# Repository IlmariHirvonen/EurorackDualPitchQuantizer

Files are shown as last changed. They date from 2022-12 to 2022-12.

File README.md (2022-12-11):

# EurorackDualPitchQuantizer
A simple Arduino and MCP4725 DAC based pitch quantizer. It might not be the best designed module or it might not work at all yet. I have yet to assemble a working unit or program the non test firmware for the microcontroller. I'll update this as the project goes along.

### Licenses
The license for hardware is under the hardware folder and for software under software folder. But in short:
Software: GPL3.0.
Hardware: CERN-OHL-S v2

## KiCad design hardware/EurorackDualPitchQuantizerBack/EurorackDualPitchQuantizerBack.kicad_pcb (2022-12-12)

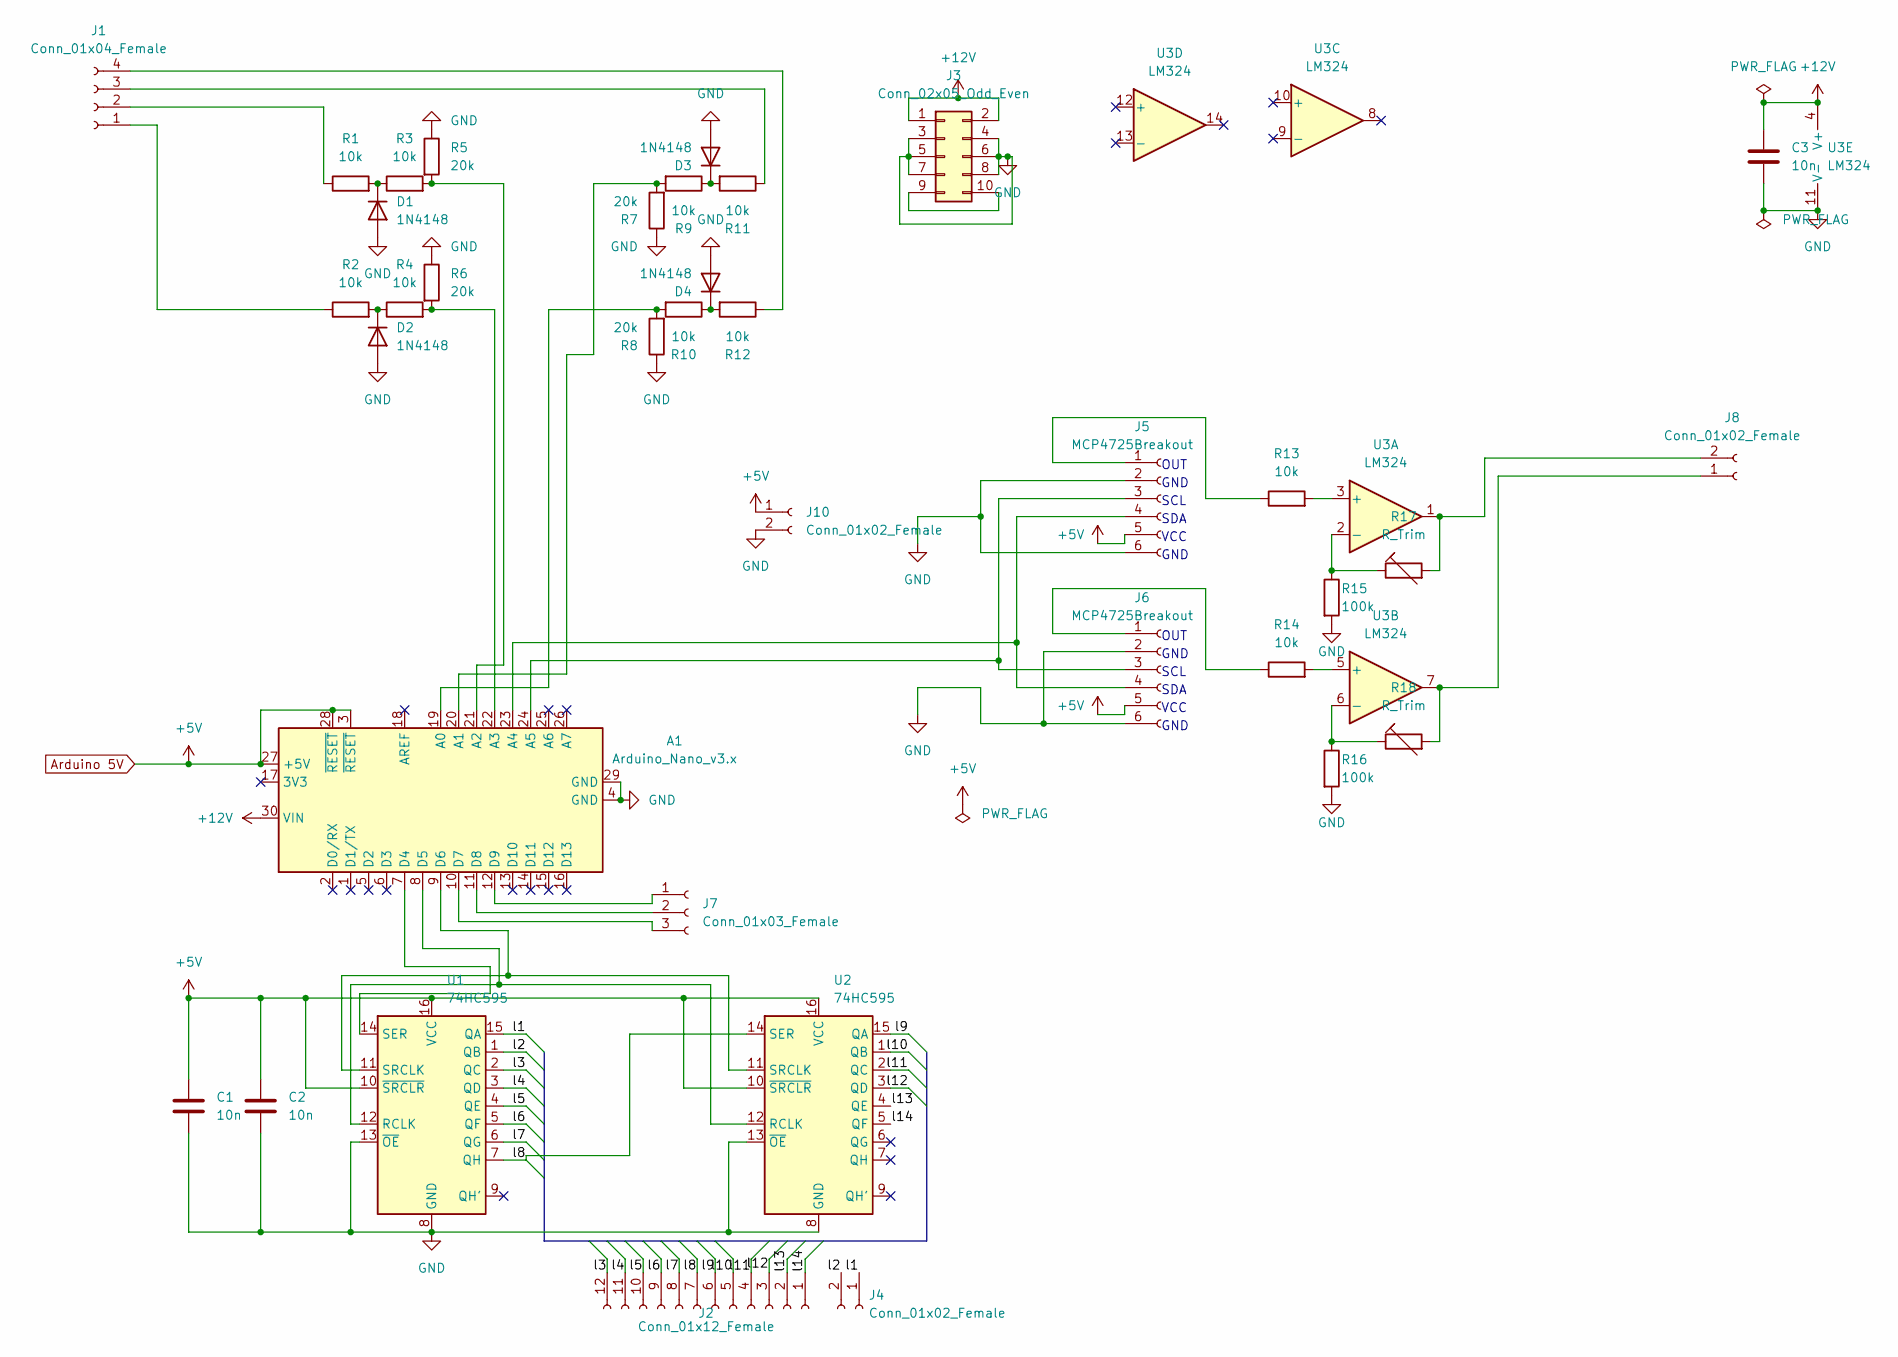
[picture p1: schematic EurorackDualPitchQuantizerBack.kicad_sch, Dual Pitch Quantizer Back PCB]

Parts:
A1: Arduino_Nano_v3.x; Arduino_Nano
C1, C2, C3: 10n; C_Disc_D3.0mm_W2.0mm_P2.50mm
D1, D2, D3, D4: 1N4148; D_DO-35_SOD27_P7.62mm_Horizontal
J1: Conn_01x04_Female; PinSocket_1x04_P2.54mm_Vertical
J2: Conn_01x12_Female; PinSocket_1x12_P2.54mm_Vertical
J3: Conn_02x05_Odd_Even; PinHeader_2x05_P2.54mm_Vertical
J4, J8: Conn_01x02_Female; PinSocket_1x02_P2.54mm_Vertical
J5, J6: MCP4725Breakout; PinSocket_1x06_P2.54mm_Vertical
J7: Conn_01x03_Female; PinHeader_1x03_P2.54mm_Vertical
J10: Conn_01x02_Female; PinHeader_1x02_P2.54mm_Vertical
R1, R2, R3, R4, R9, R10, R11, R12, R13, R14: 10k; R_Axial_DIN0207_L6.3mm_D2.5mm_P7.62mm_Horizontal
R5, R6, R7, R8: 20k; R_Axial_DIN0207_L6.3mm_D2.5mm_P7.62mm_Horizontal
R15, R16: 100k; R_Axial_DIN0207_L6.3mm_D2.5mm_P7.62mm_Horizontal
R17, R18: R_Trim; PinHeader_1x03_P2.54mm_Vertical
U1, U2: 74HC595; DIP-16_W7.62mm_Socket
U3: LM324; DIP-14_W7.62mm_Socket

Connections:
+12V: A1.30 (VIN), C3.1, J3.1, J3.2, U3.4 (V+)
/l1: J4.1, U1.15 (QA)
/l2: J4.2, U1.1 (QB)
/l3: J2.12, U1.2 (QC)
/l4: J2.11, U1.3 (QD)
/l5: J2.10, U1.4 (QE)
/l6: J2.9, U1.5 (QF)
/l7: J2.8, U1.6 (QG)
/l8: J2.7, U1.7 (QH), U2.14 (SER)
/l9: J2.6, U2.15 (QA)
/l10: J2.5, U2.1 (QB)
/l11: J2.4, U2.2 (QC)
/l12: J2.3, U2.3 (QD)
/l13: J2.2, U2.4 (QE)
/l14: J2.1, U2.5 (QF)
Arduino 5V: A1.3 (~RESET), A1.27 (+5V), A1.28 (~RESET), C1.1, C2.1, J5.5, J6.5, J10.1, U1.10 (~SRCLR), U1.16 (VCC), U2.10 (~SRCLR), U2.16 (VCC)
GND: A1.4 (GND), A1.29 (GND), C1.2, C2.2, C3.2, D1.2 (A), D2.2 (A), D3.2 (A), D4.2 (A), J3.3, J3.4, J3.5, J3.6, J3.7, J3.8, J5.2, J5.6, J6.2, J6.6, J10.2, R5.1, R6.1, R7.1, R8.1, R15.2, R16.2, U1.8 (GND), U1.13 (~OE), U2.8 (GND), U2.13 (~OE), U3.11 (V-)
unnamed: A1.7 (D4), U1.14 (SER)
unnamed: A1.8 (D5), U1.12 (RCLK), U2.12 (RCLK)
unnamed: A1.9 (D6), U1.11 (SRCLK), U2.11 (SRCLK)
unnamed: A1.10 (D7), J7.3
unnamed: A1.11 (D8), J7.2
unnamed: A1.12 (D9), J7.1
unnamed: A1.19 (A0), R8.2, R10.2
unnamed: A1.20 (A1), R7.2, R9.2
unnamed: A1.21 (A2), R3.2, R5.2
unnamed: A1.22 (A3), R4.2, R6.2
unnamed: A1.23 (A4), J5.4, J6.4
unnamed: A1.24 (A5), J5.3, J6.3
unnamed: D1.1 (K), R1.2, R3.1
unnamed: D2.1 (K), R2.2, R4.1
unnamed: D3.1 (K), R9.1, R11.2
unnamed: D4.1 (K), R10.1, R12.2
unnamed: J1.1, R2.1
unnamed: J1.2, R1.1
unnamed: J1.3, R11.1
unnamed: J1.4, R12.1
unnamed: J3.9, J3.10
unnamed: J5.1, R13.1
unnamed: J6.1, R14.1
unnamed: J8.2, R17.2, U3.1
unnamed: R13.2, U3.3 (+)
unnamed: R14.2, U3.5 (+)
unnamed: R15.1, R17.1, U3.2 (-)
unnamed: R16.1, R18.1, U3.6 (-)
unnamed: J8.1, R18.2, U3.7

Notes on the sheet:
GND
SDA
SCL
OUT
VCC

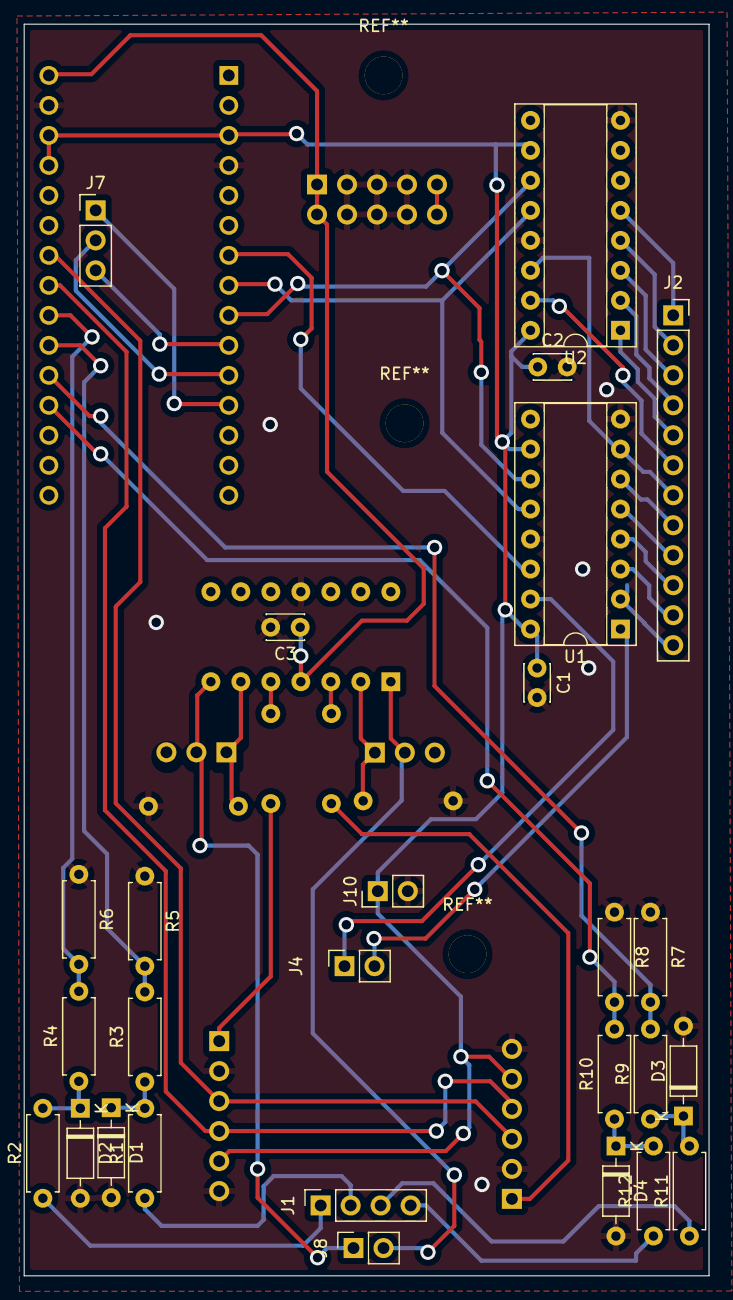
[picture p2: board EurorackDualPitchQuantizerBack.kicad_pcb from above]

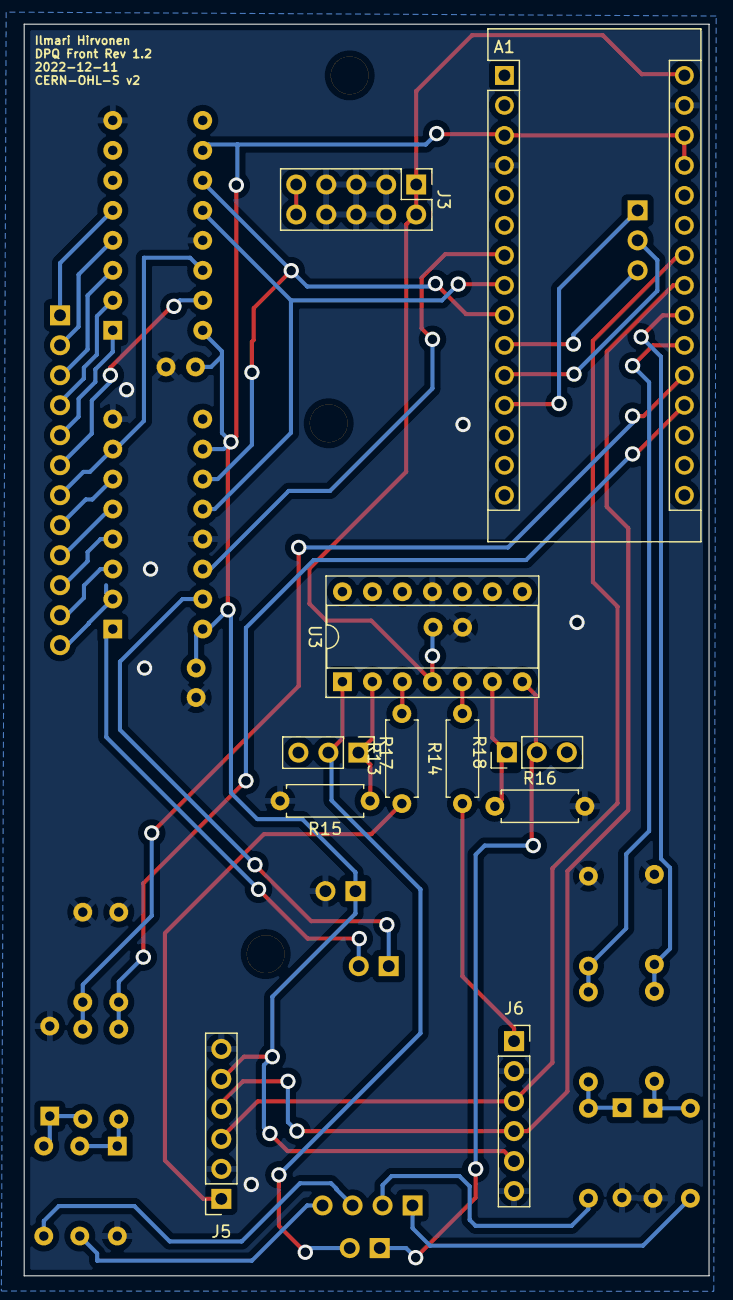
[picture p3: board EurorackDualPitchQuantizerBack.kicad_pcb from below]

Board: 2 copper layers, 58.0 x 106.0 mm, 38 parts (11 on the bottom side), 46 nets.

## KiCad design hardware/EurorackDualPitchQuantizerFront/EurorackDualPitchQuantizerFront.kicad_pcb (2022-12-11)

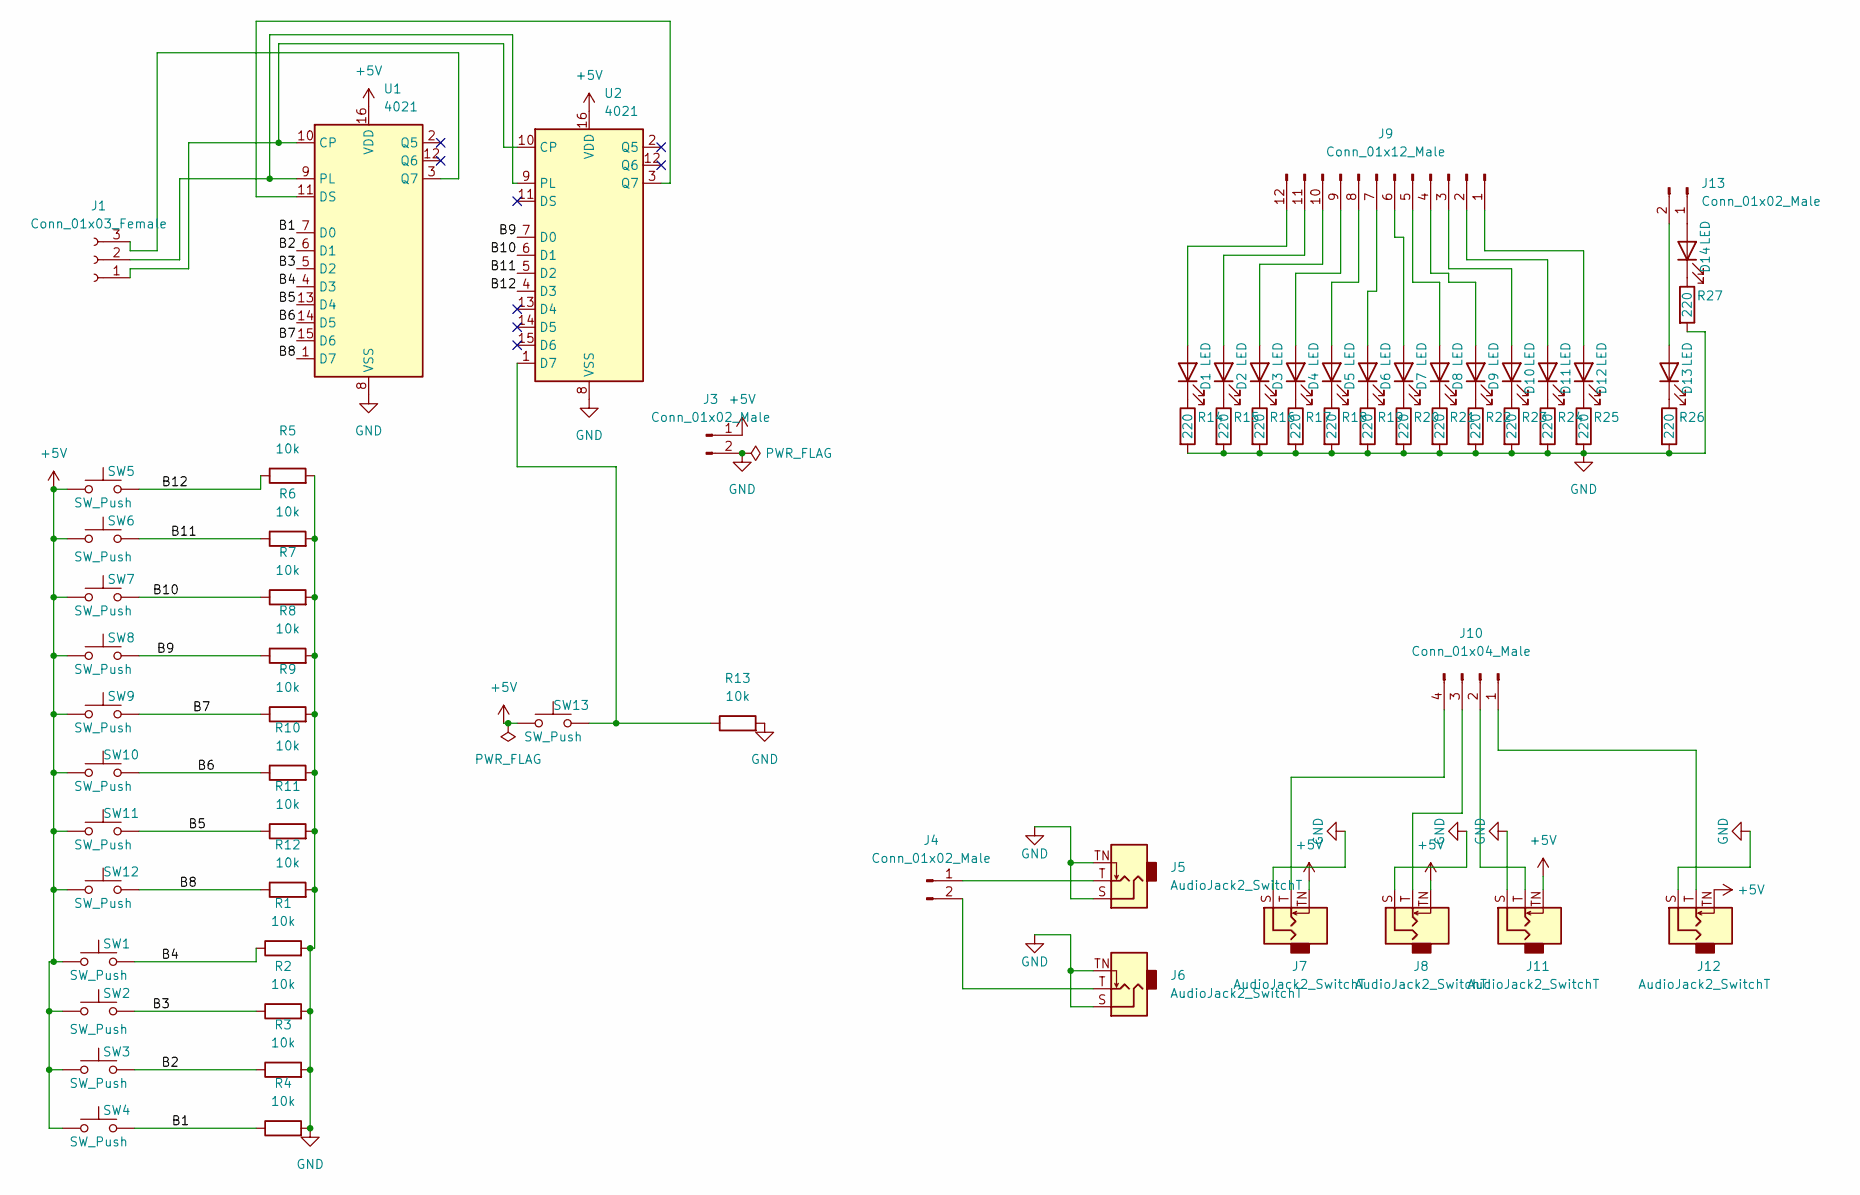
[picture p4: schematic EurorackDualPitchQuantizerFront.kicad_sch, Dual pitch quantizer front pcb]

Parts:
D1, D2, D3, D4, D5, D6, D7, D8, D9, D10, D11, D12, D13, D14: LED; LED_D3.0mm
J1: Conn_01x03_Female; PinHeader_1x03_P2.54mm_Vertical
J3, J4, J13: Conn_01x02_Male; PinHeader_1x02_P2.54mm_Vertical
J5, J6, J7, J8, J11, J12: AudioJack2_SwitchT; Thonkiconn
J9: Conn_01x12_Male; PinHeader_1x12_P2.54mm_Vertical
J10: Conn_01x04_Male; PinHeader_1x04_P2.54mm_Vertical
R1, R2, R3, R4, R5, R6, R7, R8, R9, R10, R11, R12, R13: 10k; R_Axial_DIN0207_L6.3mm_D2.5mm_P7.62mm_Horizontal
R14, R15, R16, R17, R18, R19, R20, R21, R22, R23, R24, R25, R26, R27: 220; R_Axial_DIN0207_L6.3mm_D2.5mm_P7.62mm_Horizontal
SW1, SW2, SW3, SW4, SW5, SW6, SW7, SW8, SW9, SW10, SW11, SW12, SW13: SW_Push; SW_PUSH_6mm
U1, U2: 4021; DIP-16_W7.62mm_Socket

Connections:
+5V: J3.1, J7.TN, J8.TN, J11.TN, J12.TN, SW1.1, SW2.1, SW3.1, SW4.1, SW5.1, SW6.1, SW7.1, SW8.1, SW9.1, SW10.1, SW11.1, SW12.1, SW13.1, U1.16 (VDD), U2.16 (VDD)
/B1: R4.1, SW4.2, U1.7 (D0)
/B2: R3.1, SW3.2, U1.6 (D1)
/B3: R2.1, SW2.2, U1.5 (D2)
/B4: R1.1, SW1.2, U1.4 (D3)
/B5: R11.1, SW11.2, U1.13 (D4)
/B6: R10.1, SW10.2, U1.14 (D5)
/B7: R9.1, SW9.2, U1.15 (D6)
/B8: R12.1, SW12.2, U1.1 (D7)
/B9: R8.1, SW8.2, U2.7 (D0)
/B10: R7.1, SW7.2, U2.6 (D1)
/B11: R6.1, SW6.2, U2.5 (D2)
/B12: R5.1, SW5.2, U2.4 (D3)
GND: J3.2, J5.S, J5.TN, J6.S, J6.TN, J7.S, J8.S, J11.S, J12.S, R1.2, R2.2, R3.2, R4.2, R5.2, R6.2, R7.2, R8.2, R9.2, R10.2, R11.2, R12.2, R13.2, R14.2, R15.2, R16.2, R17.2, R18.2, R19.2, R20.2, R21.2, R22.2, R23.2, R24.2, R25.2, R26.2, R27.2, U1.8 (VSS), U2.8 (VSS)
unnamed: D1.1 (K), R14.1
unnamed: D1.2 (A), J9.12
unnamed: D2.1 (K), R15.1
unnamed: D2.2 (A), J9.11
unnamed: D3.1 (K), R16.1
unnamed: D3.2 (A), J9.10
unnamed: D4.1 (K), R17.1
unnamed: D4.2 (A), J9.9
unnamed: D5.1 (K), R18.1
unnamed: D5.2 (A), J9.8
unnamed: D6.1 (K), R19.1
unnamed: D6.2 (A), J9.7
unnamed: D7.1 (K), R20.1
unnamed: D7.2 (A), J9.6
unnamed: D8.1 (K), R21.1
unnamed: D8.2 (A), J9.5
unnamed: D9.1 (K), R22.1
unnamed: D9.2 (A), J9.4
unnamed: D10.1 (K), R23.1
unnamed: D10.2 (A), J9.3
unnamed: D11.1 (K), R24.1
unnamed: D11.2 (A), J9.2
unnamed: D12.1 (K), R25.1
unnamed: D12.2 (A), J9.1
unnamed: D13.1 (K), R26.1
unnamed: D13.2 (A), J13.2
unnamed: D14.1 (K), R27.1
unnamed: D14.2 (A), J13.1
unnamed: J1.1, U1.10 (CP), U2.10 (CP)
unnamed: J1.2, U1.9 (PL), U2.9 (PL)
unnamed: J1.3, U1.3 (Q7)
unnamed: J4.1, J5.T
unnamed: J4.2, J6.T
unnamed: J10.1, J12.T
unnamed: J10.2, J11.T
unnamed: J8.T, J10.3
unnamed: J7.T, J10.4
unnamed: R13.1, SW13.2, U2.1 (D7)
unnamed: U1.11 (DS), U2.3 (Q7)

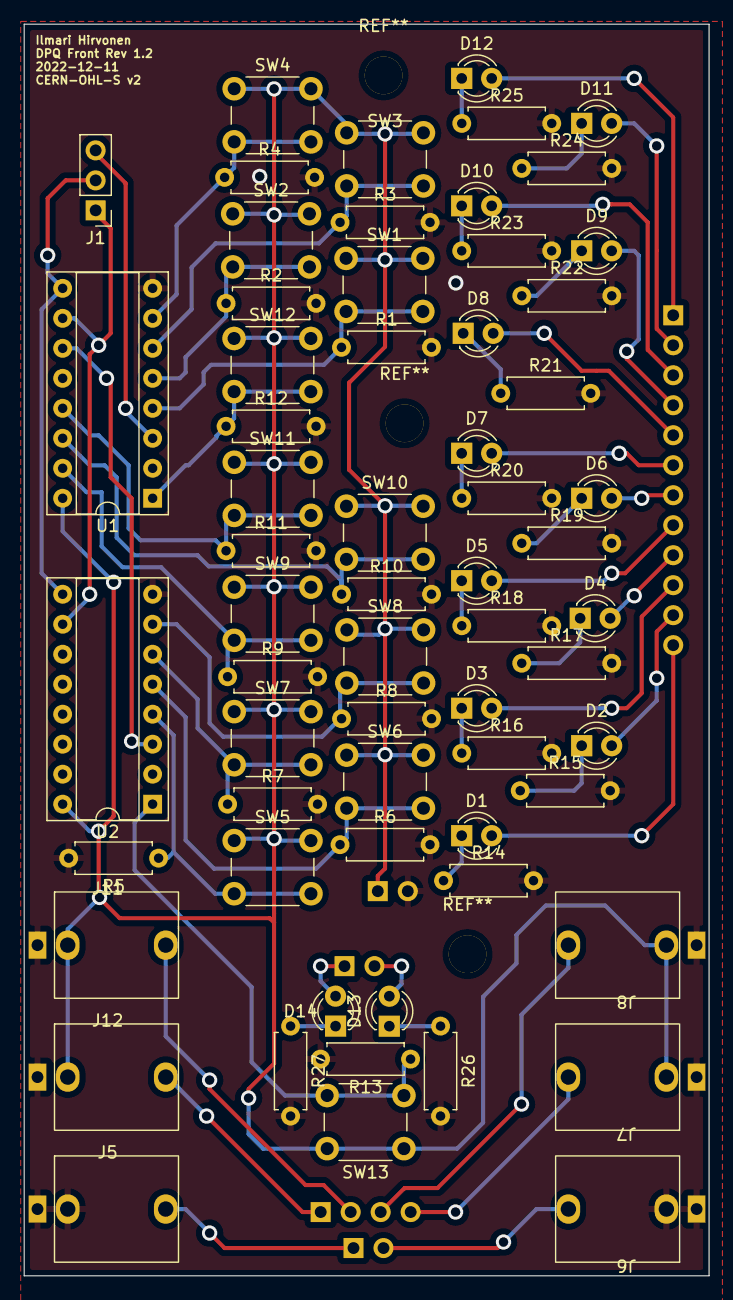
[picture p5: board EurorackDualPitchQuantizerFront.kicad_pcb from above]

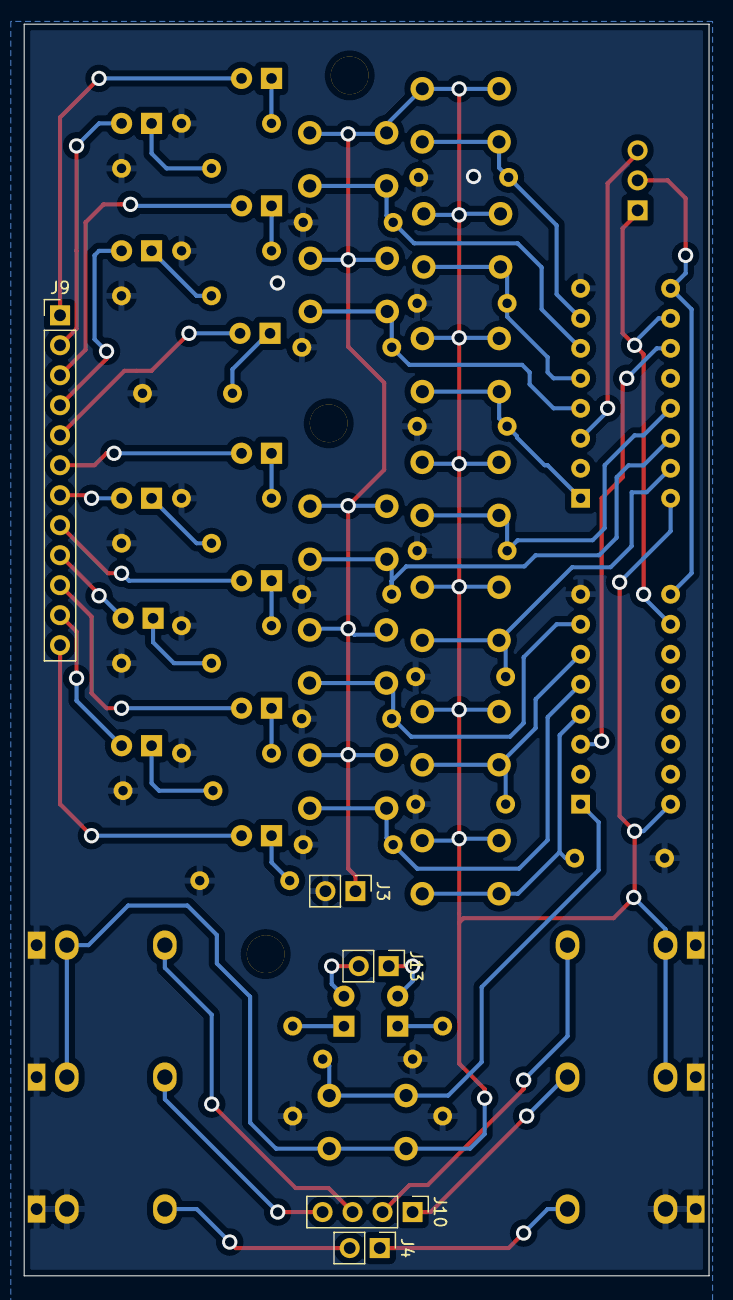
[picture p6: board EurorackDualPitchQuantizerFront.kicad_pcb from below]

Board: 2 copper layers, 58.0 x 106.0 mm, 68 parts (5 on the bottom side), 53 nets.

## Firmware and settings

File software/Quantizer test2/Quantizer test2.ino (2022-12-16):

#include <Wire.h>//Include the Wire library to talk I2C
#include <Arduino.h>
#include <AceSorting.h>

#define MCP4725_ADDR 0x60
using ace_sorting::shellSortKnuth;

int search(int arr[], int n, int x) 
{ 
    //Initialize indices for binary search 
    int i, j, index1=0, index2=n-1; 
  
    //Loop until the two indices meet 
    while (index1 <= index2) 
    { 
        //Find the midpoint of the array 
        i = (index1 + index2)/2; 
  
        //If the midpoint value matches the input value, return the index 
        if( arr[i] == x ) 
            return i; 
  
        //If the midpoint value is less than the input value, move the left index forward 
        else if( arr[i] < x ) 
            index1 = i+1; 
  
        //Otherwise move the right index backward 
        else
            index2 = i-1; 
    } 
  
    //If the two indices have crossed each other, compare the absolute values of the left and right indices 
    if (index1 > index2) 
    { 
        //If the absolute value of the left index is less than the absolute value of the right index, return the left index 
        if (abs(arr[index1]-x) < abs(arr[index2]-x)) 
            return index1; 
        
        //Otherwise, return the right index 
        else
            return index2; 
    } 
  
    //If no value is found, return -1 
    return -1; 
}

int findQuantizedNote(int input)
{
  int octave = input / 580;
  int note = search(all_notes, 12, input % 580);
}
//the octave can be found by dividing by 580 and the note by modulo 580. I need to have a list of 12 notes and do a quicker search through them. No need for sorting.

int c[]  = {0, 580, 580*2, 580*3, 580*4, 580*5, 580*6};
int cs[] = {48, 48 + 580, 48 + 580*2, 48 + 580*3, 48 + 580*4, 48 + 580*5, 48 + 580*6};
int d[]  = {97, 97 + 580, 97 + 580*2, 97 + 580*3, 97 + 580*4, 97 + 580*5, 97 + 580*6};
int ds[] = {145, 145 + 580, 145 + 580*2, 145 + 580*3, 145 + 580*4, 145 + 580*5, 145 + 580*6};
int e[]  = {193, 193 + 580, 193 + 580*2, 193 + 580*3, 193 + 580*4, 193 + 580*5, 193 + 580*6};
int f[]  = {241, 241 + 580, 241 + 580*2, 241 + 580*3, 241 + 580*4, 241 + 580*5, 241 + 580*6};
int fs[] = {290, 290 + 580, 290 + 580*2, 290 + 580*3, 290 + 580*4, 290 + 580*5, 290 + 580*6};
int g[]  = {338, 338 + 580, 338 + 580*2, 338 + 580*3, 338 + 580*4, 338 + 580*5, 338 + 580*6};
int gs[] = {387, 387 + 580, 387 + 580*2, 387 + 580*3, 387 + 580*4, 387 + 580*5, 387 + 580*6};
int a[]  = {435, 435 + 580, 435 + 580*2, 435 + 580*3, 435 + 580*4, 435 + 580*5, 435 + 580*6};
int as[] = {483, 483 + 580, 483 + 580*2, 483 + 580*3, 483 + 580*4, 483 + 580*5, 483 + 580*6};
int b[]  = {532, 532 + 580, 532 + 580*2, 532 + 580*3, 532 + 580*4, 532 + 580*5, 532 + 580*6};

//Notes in chromatic order from C to B
int all_notes[] = {0, 48, 97, 145, 193, 241, 290, 338, 387, 435, 483, 532};

//If making this into a better product there should be a way to select the notes and maybe using them to calculate
//the minimum distance between notes to reduce unesecary time looking up and sending data.
void printArray(int arr[], int arrLenght)
{
  for(int i = 0; i < arrLenght; i++)
  {
    Serial.println(arr[i]);
  }
}

int number_of_notes = 0;

//Since there are 12 buttons, each element will correspond to a button.
int keyMask1[] = [1,1,1,1,1,1,1,1,1,1,1,1];
int keyMask2[] = [1,1,1,1,1,1,1,1,1,1,1,1];

void setup() {
  number_of_notes = sizeof(all_notes)/sizeof(all_notes[0]);
  shellSortKnuth(all_notes, number_of_notes);
  

  Wire.begin();
  pinMode(A6, INPUT);
  Serial.begin(9600);
  

  printArray(all_notes, number_of_notes);
} 
int inputPin1 = A6;
float CV1_in = 0;
int CV1_pitch = 0;
int CV1_quantized = 0;
bool first_loop = true;

void loop() {

  CV1_in = analogRead(A6);
  CV1_pitch = (int)(CV1_in*2*1.5);
  //Serial.println(CV1_pitch);
  //Serial.println(CV1_quantized);
  
  //Look up and send a new note if there is a possibility that a note could change.
  if(abs(CV1_pitch - CV1_quantized) > (48/2)){
    //Serial.println(CV1_quantized);
    CV1_quantized = search(all_notes, number_of_notes, CV1_pitch);
    Wire.beginTransmission(MCP4725_ADDR);
    Wire.write(64); 
    Wire.write(CV1_quantized >> 4);        // the 8 most significant bits...
    Wire.write((CV1_quantized & 15) << 4); // the 4 least significant bits...
    Wire.endTransmission();
  }
  delay(1);
}


/*
  unsigned long startTime = micros();
  unsigned long endTime = micros();
  Serial.println("time to run");
  Serial.println(endTime-startTime);
  Serial.println("-------");
*/

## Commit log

2022-12-06 fixed project structure
    [EurorackDualPitchQuantizerFront.kicad_pcb, EurorackDualPitchQuantizerFront.kicad_sch, EurorackDualPitchQuantizerFrontPanel.kicad_pcb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]
2022-12-11 made another version that is not viable since it is too tall
    [EurorackDualPitchQuantizerBack.kicad_pcb, EurorackDualPitchQuantizerFront.kicad_pcb, EurorackDualPitchQuantizerFront.kicad_sch]
2022-12-11 Got Rev 1.2 complete. It should be manufacturable and fit into eurorack standards.
    [EurorackDualPitchQuantizerBack.kicad_pcb, EurorackDualPitchQuantizerBack.kicad_sch, EurorackDualPitchQuantizerFront.kicad_pcb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]
2022-12-12 minor modifications
    [EurorackDualPitchQuantizerBack.kicad_pcb]

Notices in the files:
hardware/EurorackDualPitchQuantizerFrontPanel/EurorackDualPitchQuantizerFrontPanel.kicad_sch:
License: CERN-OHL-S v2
